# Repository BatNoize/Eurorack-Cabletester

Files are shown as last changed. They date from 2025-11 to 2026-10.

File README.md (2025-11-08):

# Arduino 10/16 pin Eurorack IDC Power Cable Tester

## History
1. Forked from https://github.com/tomarus/cabletester with slight modifications to circuit and software (mainly order of connections), and with PCB layout added.
2. This is froked from https://gitlab.com/rsholmes/cabletester. 

## Changes
- Modified to SMD resistors.
- The single capacitor C1 is still a THT capacitor. I overlooked that. However, an 0805 SMD component can easily be used.
- Add M3 mounting holes.
- An OpenSCAD drawing for a 3D enclosure to protect the underside of the circuit boards has been added. (The OpenSCAD code is not beautiful but it's functional)

## Features
It only tests (max) 8 wires because of how they're wired in eurorack.
It can detect shorted cables or faulty/unconnected wires.

This project uses a 128x64 OLED I2C display module with four interface pins: GND, +12V, SCL, and SDA. It is a monochrome display although it is available in a version with a yellow and blue overlay as seen in the photos. Note that the OLED pinout sometimes is GND-VCC-SCL-SDA and sometimes VCC-GND-SCL-SDA. The initial run of boards assumed the latter pinout; the present design has footprints for both.
These modules are available from the "usual suspects" on Amazon, eBay, AliExpress, etc. I have one of these (GND-VCC-SCL-SDA) and one of these (VCC-GND-SCL-SDA). They do not seem to be available from any established vendors like Mouser, DigiKey, Tayda, Adafruit, or SparkFun. Please make sure you have a source for the display before proceeding with this project!
Code uses these libraries:

- https://github.com/adafruit/Adafruit_SSD1306
- https://github.com/adafruit/Adafruit-GFX-Library

## Original Schematic

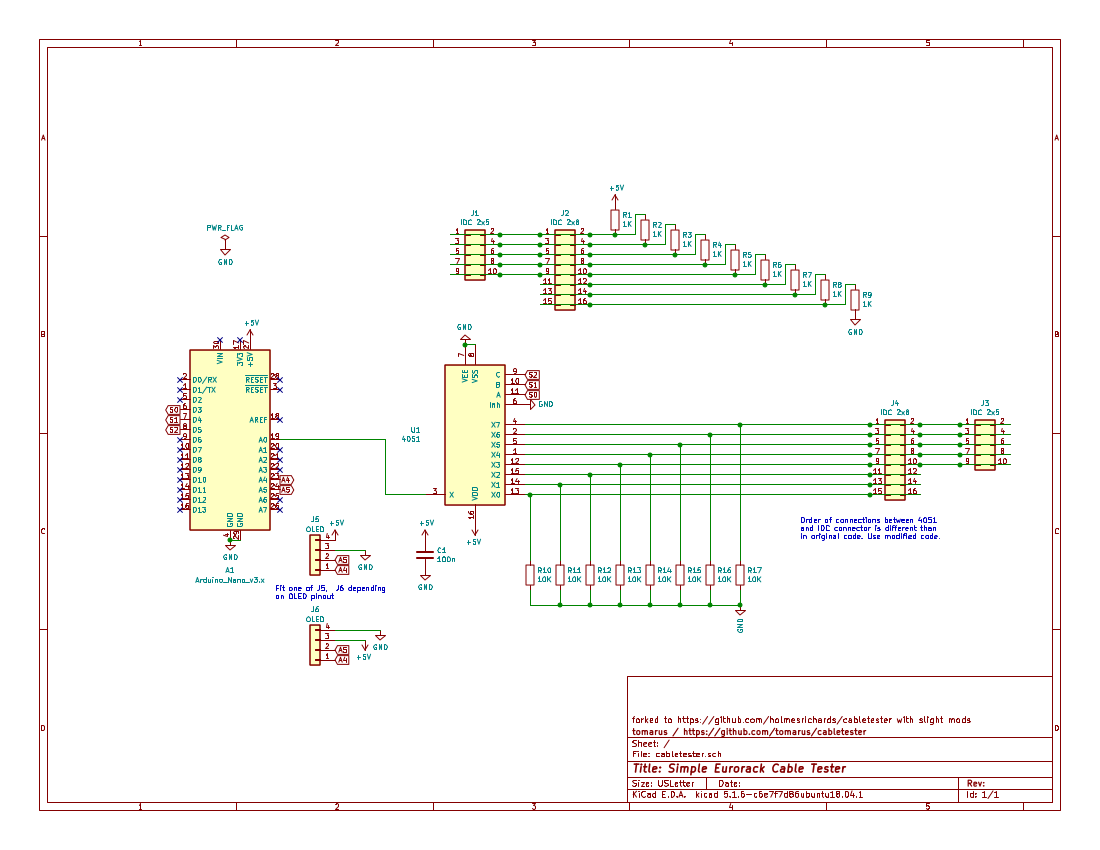
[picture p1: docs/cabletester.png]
Schematic


## PCB

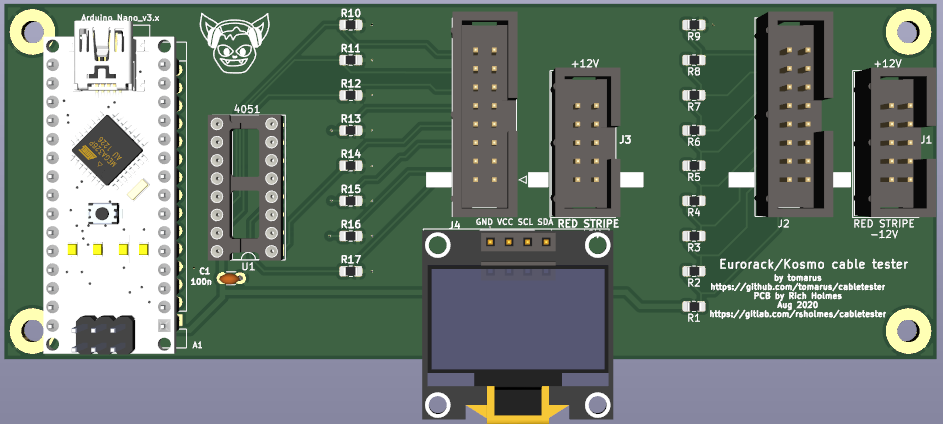
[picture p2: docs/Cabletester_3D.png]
PCB


## Case

Here is the preview openSCAD Case for the cabletester.
You need 4x M3x10mm countersunk screws and 4x M3 nuts.

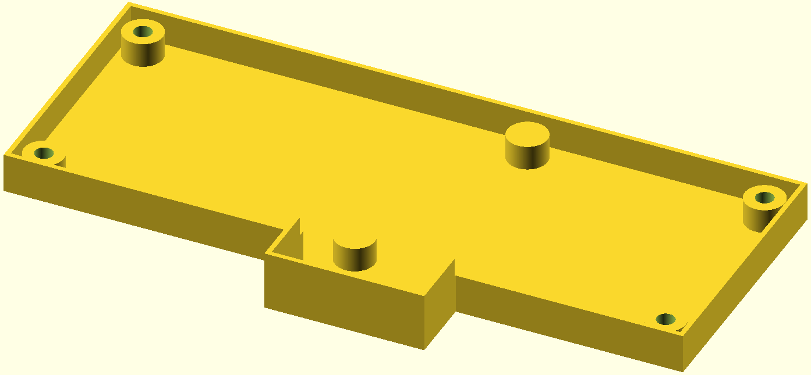
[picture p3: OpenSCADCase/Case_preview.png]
OpenScad Case w. Frame


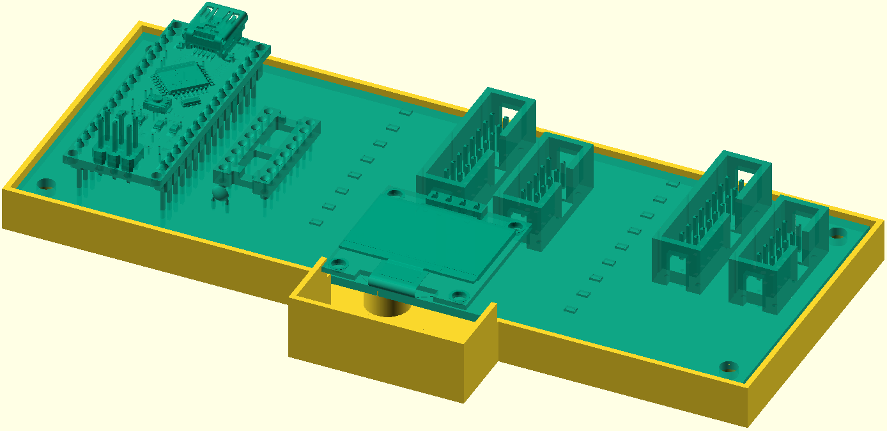
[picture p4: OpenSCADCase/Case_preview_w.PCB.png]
"OpenScad Case w. PCB"


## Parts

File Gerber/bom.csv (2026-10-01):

Designator | Footprint | Quantity | Value | LCSC Part #
A1 | Arduino_Nano | 1 | Arduino_Nano_v3.x
C1 | 0805 | 1 | 100n
J1, J3 | Power_Header | 2 | IDC 2x5
J2, J4 | IDC-Header_2x08_P2.54mm_Vertical | 2 | IDC 2x8
J5, J6 | PinSocket_1x04_P2.54mm_Vertical | 2 | 4 pin header
R1, R2, R3, R4, R5, R6, R7, R8, R9 | 0805 | 9 | 1K
R10, R11, R12, R13, R14, R15, R16, R17 | 0805 | 8 | 10K
U1 | DIP-16_W7.62mm_Socket_LongPads | 1 | 4051
U2 | OLED_MC096_128x64 i2c_(Only Display No THT) | 1 | DISP

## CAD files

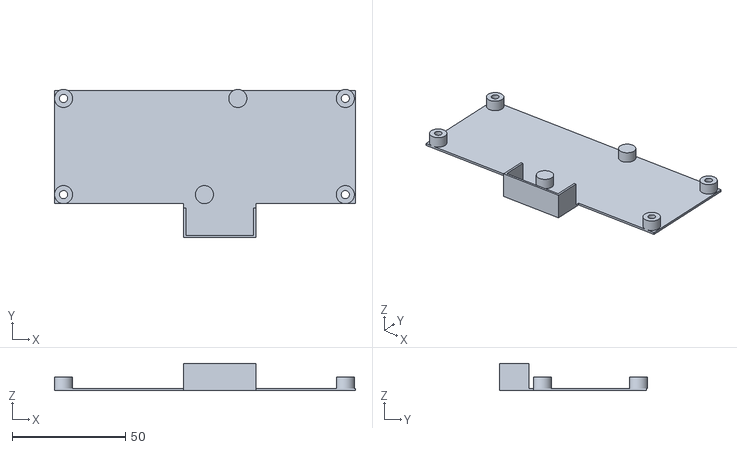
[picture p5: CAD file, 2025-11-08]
OpenSCADCase/Case.stl
133.0 x 65.5 x 12.0

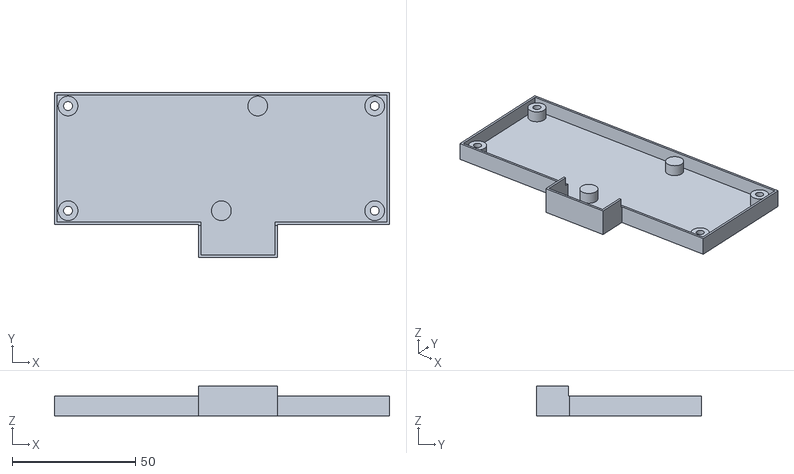
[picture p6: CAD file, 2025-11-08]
OpenSCADCase/Case_w.frame.stl
136.0 x 67.0 x 12.0

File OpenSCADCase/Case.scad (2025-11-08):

//translate([-60.5, 84.5, 5]){
//    color(([0,125,100,200]/255)){
//    import("cabletester.stl", convexity=1);
//    }
//}

module screw_hole(){
    translate([0, 0, -0.01]){
        cylinder(1.7, 3, 1.6, false, $fn=360);
        translate([0, 0, 1]){
            cylinder(12, 1.8,1.8, false, $fn=360);
        }
    }
    translate([0, 0, -2.4]){
    cylinder(2.4, 3, 3, false, $fn=360);
    }
}

module all_screw_holes(){
    translate([4, 4, 0.9]){
        translate([0, 0, 0]){
        screw_hole();
        }
        translate([124.5, 0, 0]){
        screw_hole();
        }
        translate([0, 42.5, 0]){
        screw_hole();
        }
        translate([124.5, 42.5, 0]){
        screw_hole();
        }
    }
}
module frame(){
    translate([-1.5, -1.5, -0.5]){
        cube([1, 52.5, 8]);
    }
    translate([133.5, -1.5, -0.5]){
        cube([1, 52.5, 8]);
    }
    translate([-1.5, 51, -0.5]){
        cube([136, 1, 8]);
    }
    translate([-1.5, -1.5, -0.5]){
        cube([59.5, 1, 8]);
    }
    translate([88, -1.5, -0.5]){
        cube([46.5, 1, 8]);
    }
}

radius = 4;
module platte(){
    translate([-0.5, -0.5, -0.5]){
        cube([134, 51.5, 1.5]);
    }
    translate([4, 4, 1]){
        translate([0, 0, 0]){
        
        cylinder(5, radius, radius, false, $fn=360);
        }
        translate([124.5, 0, 0]){
        cylinder(5, radius, radius, false, $fn=360);
        }
        translate([0, 42.5, 0]){
        cylinder(5, radius, radius, false, $fn=360);
        }
        translate([124.5, 42.5, 0]){
        cylinder(5, radius, radius, false, $fn=360);
        }
        translate([77, 42.5, 0]){
        cylinder(5, radius, radius, false, $fn=360);
        }
        translate([62.25, 0, 0]){
        cylinder(5, radius, radius, false, $fn=360);
        }
    }
    translate([57, -15, -0.5]){
        cube([32, 17, 1.5]);
        cube([1, 13, 12]);
        cube([32, 1, 12]);
        translate([31, 0, 0]){
            cube([1, 13, 12]);
            translate([0, 12, 0]){
                cube([1, 2.5, 8]);
            }
        }
        translate([0, 12, 0]){
            cube([1, 2.5, 8]);
        }
    }
}


difference(){
    platte();
    all_screw_holes();
}
frame();

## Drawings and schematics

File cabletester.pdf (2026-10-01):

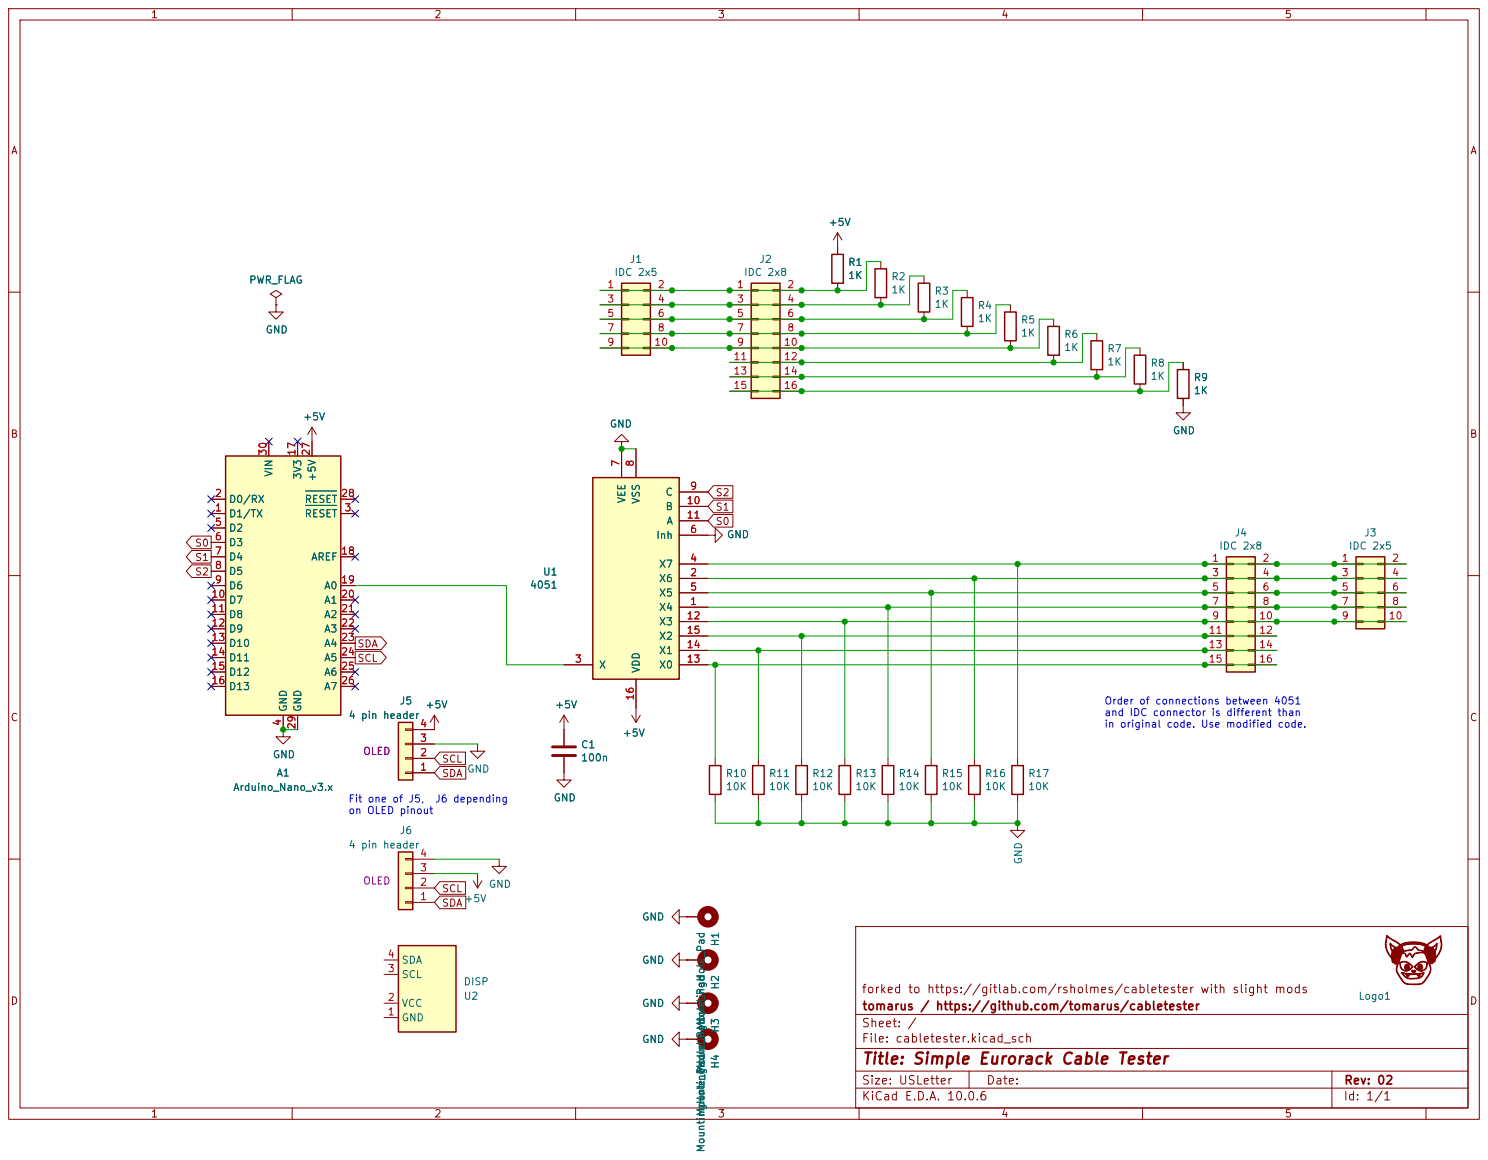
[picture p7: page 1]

10K +5V PWR_FLAG
A7 26 +5V 27 RESET 28 GND 29 VIN 30 GND

in original code. Use modified code. GND U1

and IDC connector is different than

Fit one of J5, J6 depending

forked to https://gitlab.com/rsholmes/cabletester with slight mods GND

tomarus / https://github.com/tomarus/cabletester
Sheet: /
File: cabletester.kicad_sch
Title: Simple Eurorack Cable Tester

Size: USLetter | Rev: 02
KiCad E.D.A. 10.0.6 | Id: 1/1

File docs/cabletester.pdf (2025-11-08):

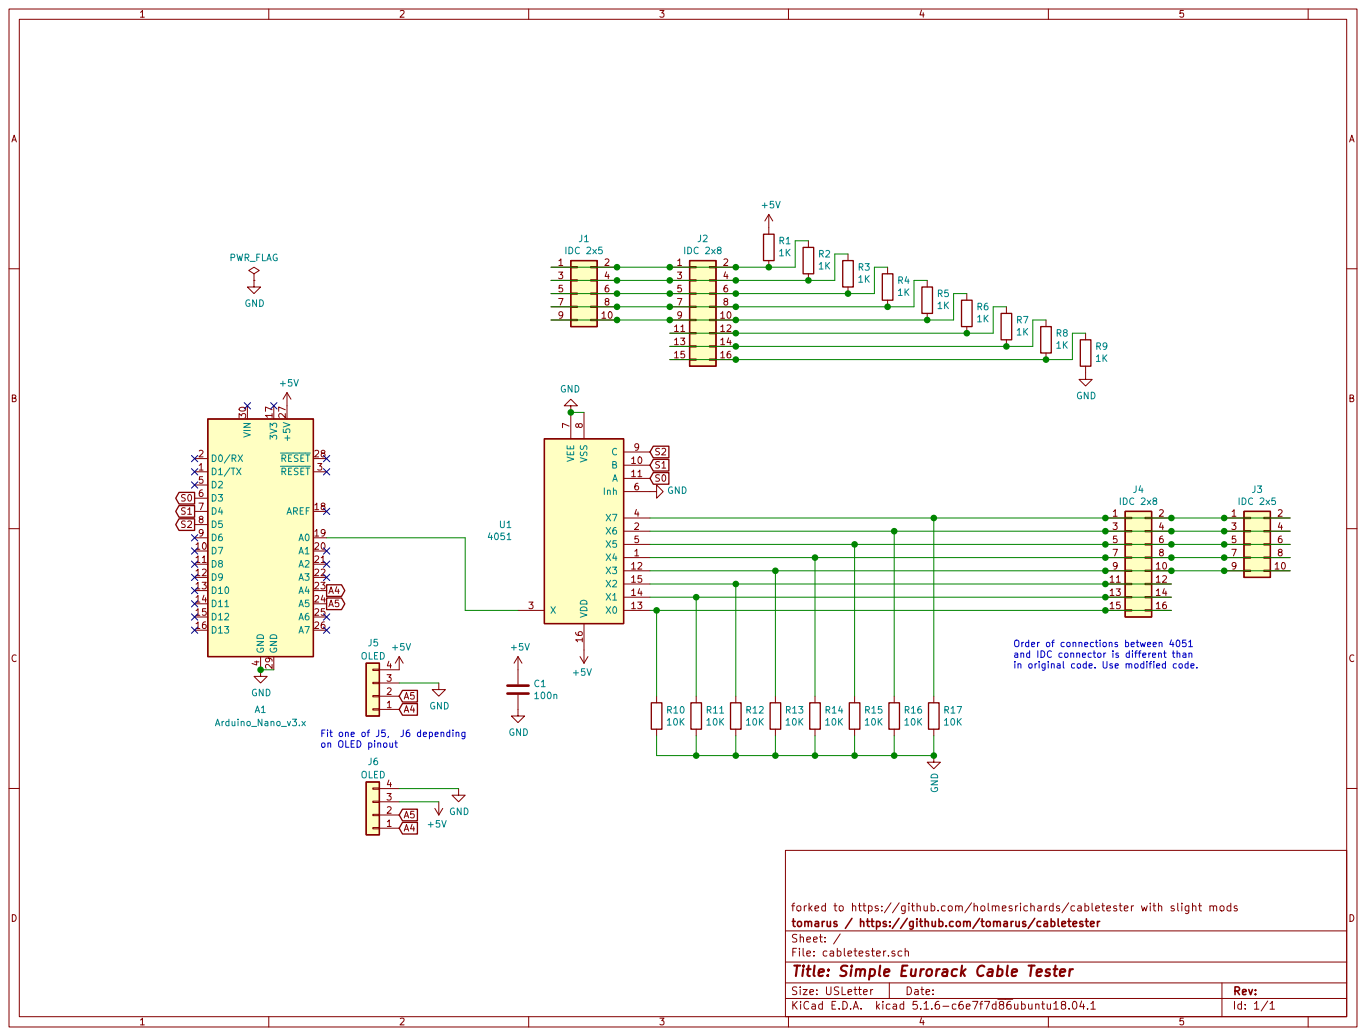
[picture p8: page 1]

and IDC connector is different than
in original code. Use modified code.

Fit one of J5, J6 depending
on OLED pinout

forked to https://github.com/holmesrichards/cabletester with slight mods
Id: 1/1 Title: Simple Eurorack Cable Tester File: cabletester.sch Sheet: / tomarus / https://github.com/tomarus/cabletester

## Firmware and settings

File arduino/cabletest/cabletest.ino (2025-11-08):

#include <Adafruit_SSD1306.h>

#define OLED_ADDR 0x3C
Adafruit_SSD1306 display(128, 64);

#define PIN_4051_S0 3
#define PIN_4051_S1 4
#define PIN_4051_S2 5
#define PIN_4051_A A0

// set DEBUG to true to display raw ADC values instead of just "OK"
const bool DEBUG = false;

const char *labels[] = {
	"-12v", "GND1", "GND2", "GND3", "+12v", "+5v", "GATE", "CV"};

// map 4051 input pins to display order
// must match label order
// see read_values()
// this is really hacky and ugly and depends on your wiring
// Index is MUX pin, value is IDC pin (0-7)
const int order[] = {
	7, // cv
	6, // gate
	5, // +5v
	4, // +12v
	3, // gnd3
	2, // gnd2
	1, // gnd1
	0  // -12v
};

// allow some fluctuation on our ADC
const int margin = 20;

// expected values (+/- margin)
// might need some tweaking
// this is really hacky too
const int expect[] = {
	746, 544, 395, 286, 204, 130, 80, 35};

const int open_threshold = 15;

int cable_status = 0;
int prev_status = -1;
const char *statuses[] = {
	"CABLE OK",
	"NO CABLE",
	"SHORTED",
	"BAD CABLE"};

int values[] = {1, 1, 1, 1, 1, 1, 1, 1};
int newvalues[] = {0, 0, 0, 0, 0, 0, 0, 0};

void setup()
{
    pinMode(PIN_4051_S0, OUTPUT);
  pinMode(PIN_4051_S1, OUTPUT);
  pinMode(PIN_4051_S2, OUTPUT);
  Serial.begin(9600);
  Serial.println("beg setup");

  display.begin(SSD1306_SWITCHCAPVCC, OLED_ADDR); 
  display.clearDisplay();
  draw_status();
  
  display.setTextColor(WHITE, BLACK);
  display.setTextSize(1);
  for (int i = 0; i < 8; i++)
  {
    int x = (i & 3) * 32;
    int y = i < 4 ? 18 : 42;
    display.setCursor(x + 4, y);
    display.print(labels[i]);
  }
  
	hdotline(39);
  vdotline(31);
  vdotline(63);
  vdotline(95);
  display.display();
  Serial.println("end setup");
}
void setupx()
{
	pinMode(PIN_4051_S0, OUTPUT);
	pinMode(PIN_4051_S1, OUTPUT);
	pinMode(PIN_4051_S2, OUTPUT);

	display.begin(SSD1306_SWITCHCAPVCC, OLED_ADDR);
	display.clearDisplay();

	draw_status();

	display.setTextColor(WHITE, BLACK);
	display.setTextSize(1);
	for (int i = 0; i < 8; i++)
	{
		int x = (i & 3) * 32;
		int y = i < 4 ? 18 : 42;
		display.setCursor(x + 4, y);
		display.print(labels[i]);
	}

	hdotline(39);
	vdotline(31);
	vdotline(63);
	vdotline(95);
	display.display();

}

void loop()
{
 	read_values(); 
	check_status(); 
//
 	display.setTextSize(1); 
 	for (int i = 0; i < 8; i++) 
 	{ 
 		draw_value(i); 
 } 
 	draw_status(); 
 	display.display(); 
}

void hdotline(int y)
{
	for (int i = 1; i < display.width(); i += 2)
	{
		display.drawPixel(i, y, SSD1306_WHITE);
	}
}

void vdotline(int x)
{
	for (int i = 17; i < display.height(); i += 2)
	{
		display.drawPixel(x, i, SSD1306_WHITE);
	}
}

// inmargin checks if value is within the expected range
bool inmargin(const int value, const int expect)
{
	return value > expect - margin && value < expect + margin;
}

// check_status checks for shorts, nr of unconnected wires, etc
void check_status()
{
	int allok = 0;
	int nc = 0;
	int shrt = 0;

	for (int i = 0; i < 8; i++)
	{
		int prev = i == 0 ? 7 : i - 1;
		int next = i == 7 ? 0 : i + 1;

		if (values[i] < open_threshold)
		{
			nc++;
		}
		else if (inmargin(values[i], values[prev]) || inmargin(values[i], values[next]))
		{
			shrt++;
		}
		else if (inmargin(values[i], expect[i]))
		{
			allok++;
		}
	}

	// advanced AI to decide on the cable status
	if (allok == 8 || (allok == 5 && nc == 3))
	{
		// everything should be ok
		cable_status = 0;
	}
	else if (nc == 8)
	{
		// no cable
		cable_status = 1;
	}
	else if (shrt > 0)
	{
		// shorted somewhere
		cable_status = 2;
	}
	else
	{
		// otherwise a bad cable
		cable_status = 3;
	}

}

// draw_status renders the global status on top of the screen
void draw_status()
{
	if (cable_status != prev_status)
	{
		prev_status = cable_status;
		display.setTextSize(2);
		display.setCursor(0, 0);
		display.print("          ");
		display.setCursor(0, 0);
		display.print(statuses[cable_status]);
	}
}

// align_value right aligns a 4-digit number for a 6px font width.
void align_value(int x, int y, int v)
{
	int off = v < 10 ? 18 : v < 100 ? 12 : v < 1000 ? 6 : 0;
	display.setCursor(x + off, y);
	display.print(v);
}

// draw_value renders one of the eight display boxes.
void draw_value(const int n)
{
	if (newvalues[n] == values[n])
		// return early, do nothing if the value isn't changed
		return;

	values[n] = newvalues[n];
	int v = values[n];

	int x = (n & 3) * 32;
	int y = n < 4 ? 28 : 52;
	display.setCursor(x, y);
	display.print("     ");

	if (v < 5)
	{
		// return early, 0 volt, unconnected wire,
		// display nothing for unconnected wires
		return;
	}

	int prev = n == 0 ? 7 : n - 1;
	int next = n == 7 ? 0 : n + 1;
	if (values[n] >= open_threshold && (inmargin(values[n], values[prev]) || inmargin(values[n], values[next])))
	{
		// If our next or previous value is the same (+/- margin)
		// there is probably a short circuit.
		display.setCursor(x + 1, y);
		display.print("SHORT");
	}
	else if (inmargin(values[n], expect[n]))
	{
		// Measurements are within limits
		// Display OK or it's raw value
		if (DEBUG)
		{
			align_value(x + 4, y, v);
		}
		else
		{
			display.setCursor(x + 16, y);
			display.print("OK");
		}
	}
	else if (values[n] >= open_threshold)
	{
		// Display raw ADC value if out of limits.
		align_value(x + 4, y, v);
	}
}

// myAnalogRead reads the analog input twice
// to stabilize the ADC input before returning
// a value.
int myAnalogRead(int pin)
{
	analogRead(pin);
	return analogRead(pin);
}

// read_values updates all values from the 4051 mux.
void read_values()
{
	for (int i = 0; i < 8; i++)
	{
		digitalWrite(PIN_4051_S0, i & 1);
		digitalWrite(PIN_4051_S1, i & 2);
		digitalWrite(PIN_4051_S2, i & 4);
		newvalues[order[i]] = myAnalogRead(PIN_4051_A);
	}
}

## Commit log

2026-10-01 THT-Cap -> SMD-Cap, add gerber & schematic
    [cabletester.kicad_pcb, cabletester.kicad_sch]
2026-10-01 add production data
    [bom.csv, designators.csv, positions.csv]
